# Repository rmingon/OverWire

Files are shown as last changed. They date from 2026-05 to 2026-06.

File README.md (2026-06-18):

# OverWire

**Cut the cord, keep the control.** 
OverWire is a specialized, open-source hardware bridge designed to liberate your STM32 development process. By coupling a powerful ESP32-WROOM-32 module with a dedicated SWD (Serial Wire Debug) interface, OverWire allows you to flash and debug STM32 targets completely wirelessly.

Whether your target is locked inside an enclosure, mounted on a moving robot, or just sitting across the room, OverWire brings the programming interface directly to you over Wi-Fi.

### Real
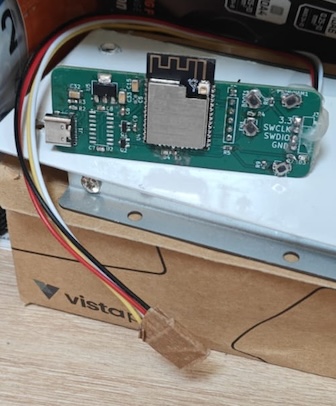
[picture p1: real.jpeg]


---
## Features

* **ESP32 at the Core:** Powered by the robust ESP32-WROOM-32 module, providing reliable 2.4 GHz Wi-Fi and Bluetooth connectivity for Over-The-Air (OTA) target flashing.
* **Dedicated SWD Port:** A clean 4-pin header (`3.3V`, `SWCLK`, `SWDIO`, `GND`) ready to hook directly into your STM32 target.
* **USB Type-C Interface:** Modern USB-C connector backed by a CH340C USB-to-UART bridge for painless initial flashing and serial debugging of the ESP32 itself.
* **Auto-Program Circuit:** Features the standard dual-BSS138 (DTR/RTS) auto-reset circuit, meaning you don't need to hold down buttons to flash the ESP32.
* **On-Board LDO:** AMS1117-3.3V regulator safely steps down the 5V USB power to a stable 3.3V for the ESP32 and SWD target.
* **Tactile Control:** Includes `EN` and `BOOT` buttons for the ESP32, plus two programmable user buttons (`TOP1`, `PROGRAM1`) mapped to `IO15` and `IO16` for custom firmware triggers.
* **Status LEDs:** Two user-controllable LEDs mapped to `IO12` and `IO13` for quick visual feedback (e.g., Wi-Fi connected, Flashing target, Error).

## Pinout & Connections

### Target SWD Interface (J3)
| Pin | Name | Description |
| :--- | :--- | :--- |
| 1 | **+3V3** | 3.3V Power Output to target (from AMS1117) |
| 2 | **SWCLK** | Serial Wire Clock (Connects to ESP32) |
| 3 | **SWDIO** | Serial Wire Debug Data I/O (Connects to ESP32) |
| 4 | **GND** | Common Ground |

### Extension / Debug Header (J2)
Provides access to `5V`, `GND`, and the ESP32 UART (`TX-PROG`, `RX-PROG`) for external communication or secondary programming.

## Gallery

### 3D Render
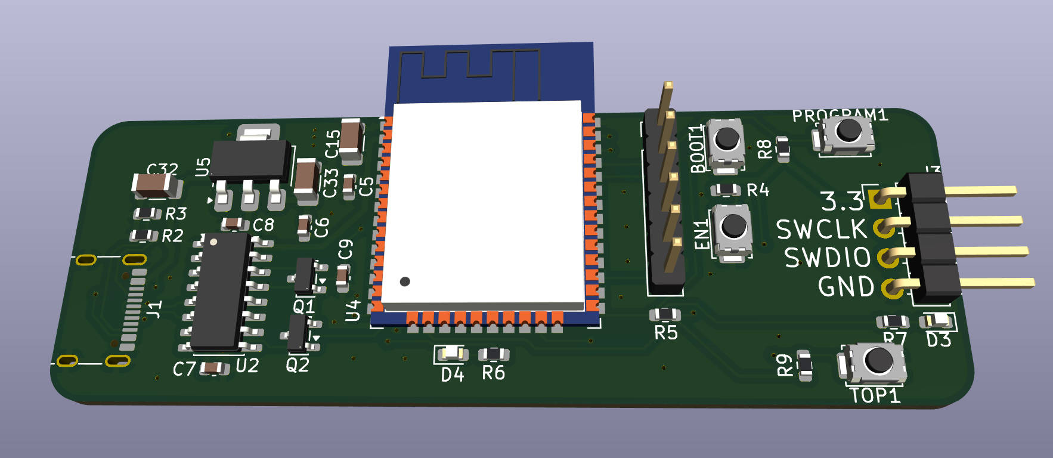
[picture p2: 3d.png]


### PCB Layout
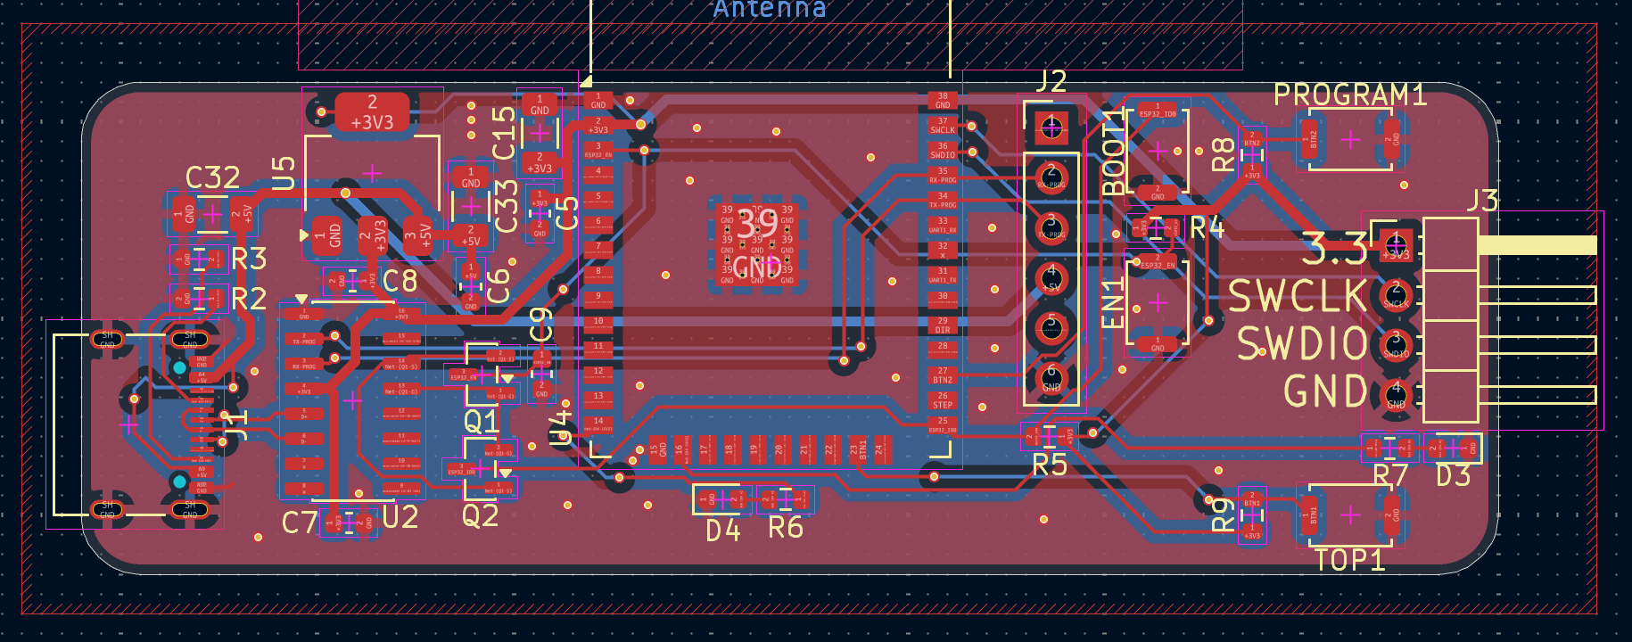
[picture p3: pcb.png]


### Schematic
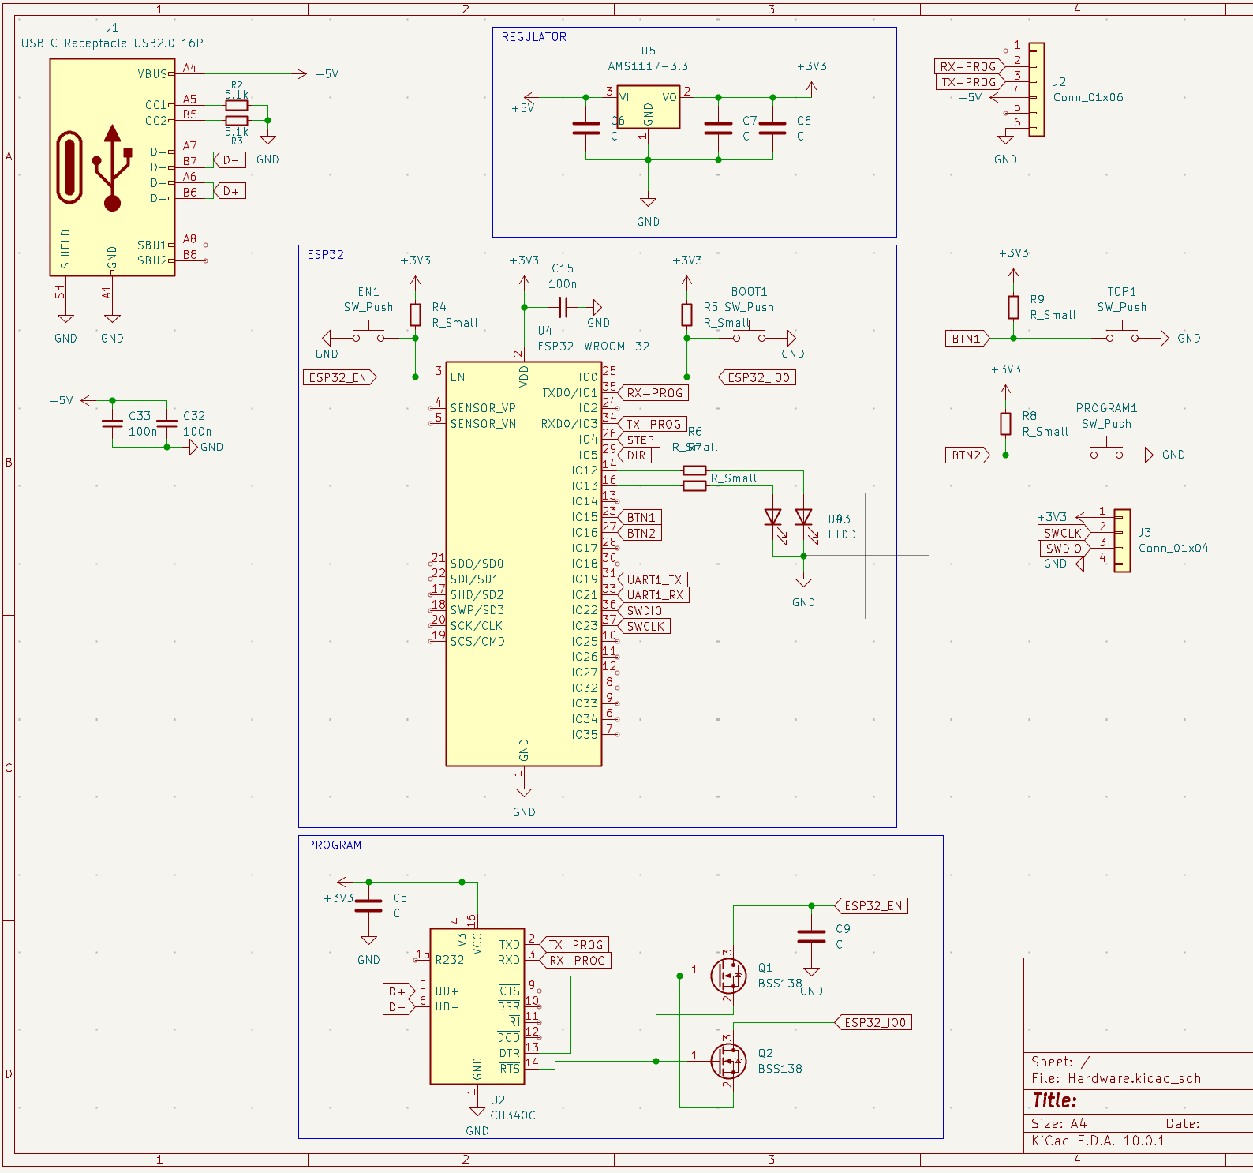
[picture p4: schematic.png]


## Getting Started

1. Connect OverWire to your PC via a USB Type-C cable.
2. Flash the ESP32 with your preferred wireless SWD firmware (such as a Wi-Fi BlackMagic Probe port or custom TCP-to-SWD bridge).
3. Connect the `J3` SWD header to your STM32 target.
4. Connect to the ESP32 over Wi-Fi and start flashing your STM32 remotely!

---

## License

This hardware design is released under the **Creative Commons Attribution-NonCommercial 4.0 International** (CC BY-NC 4.0) license. 
You are free to view, use, and modify this design for **personal, non-commercial** purposes only. You may **not** use this material for commercial purposes (such as manufacturing and selling the boards) without explicit written permission from the original author.

*Designed with KiCad.*

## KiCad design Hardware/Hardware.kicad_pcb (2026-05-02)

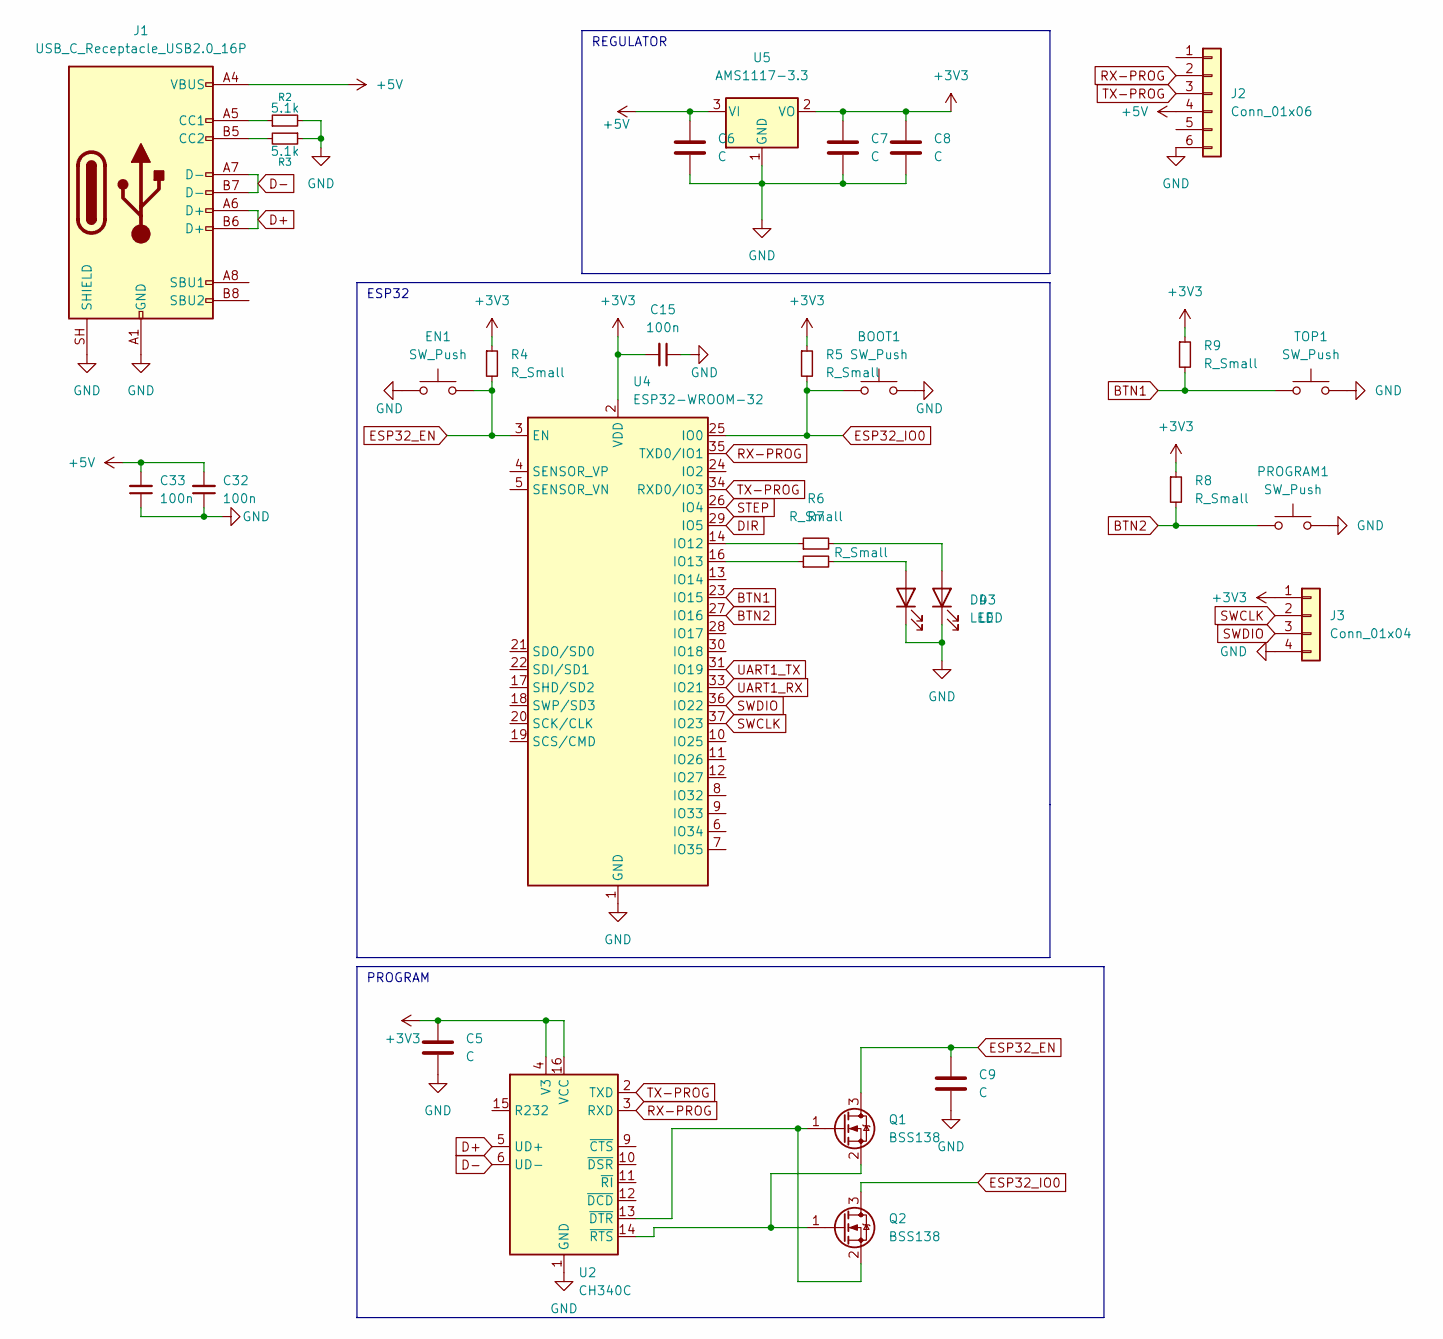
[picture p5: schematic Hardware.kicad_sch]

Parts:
BOOT1: SW_Push; SW_Push_SPST_NO_Alps_SKRK; LCSC C398053
C5, C6, C8: C; C_0603_1608Metric; LCSC C30926
C7, C9: C; C_0603_1608Metric; LCSC C19702
C15, C32, C33: 100n; C_1206_3216Metric
D3: LED; LED_0603_1608Metric; LCSC C19171301
D4: LED; LED_0603_1608Metric; LCSC C434425
EN1: SW_Push; SW_Push_SPST_NO_Alps_SKRK; LCSC C398053
J1: USB_C_Receptacle_USB2.0_16P; USB_C_Receptacle_G-Switch_GT-USB-7010ASV
J2: Conn_01x06; PinHeader_1x06_P2.54mm_Vertical
J3: Conn_01x04; PinHeader_1x04_P2.54mm_Horizontal
PROGRAM1: SW_Push; SW_Push_SPST_NO_Alps_SKRK; LCSC C398053
Q1, Q2: BSS138; SOT-23; LCSC C7420338
R2, R3: 5.1k; R_0603_1608Metric
R4, R5, R8, R9: R_Small; R_0603_1608Metric; LCSC C98220
R6, R7: R_Small; R_0603_1608Metric; LCSC C2906975
TOP1: SW_Push; SW_Push_SPST_NO_Alps_SKRK; LCSC C398053
U2: CH340C; SOIC-16_3.9x9.9mm_P1.27mm; LCSC C84681
U4: ESP32-WROOM-32; LCSC C82899
U5: AMS1117-3.3; SOT-223-3_TabPin2; LCSC C6186

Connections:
+3V3: C5.1, C7.1, C8.1, C15.2, J3.1, R4.1, R5.1, R8.1, R9.1, U2.4 (V3), U2.16 (VCC), U4.2 (VDD), U5.2 (VO)
+5V: C6.1, C32.2, C33.2, J1.A4 (VBUS), J1.A9 (VBUS), J1.B4 (VBUS), J1.B9 (VBUS), J2.4, U5.3 (VI)
BTN1: R9.2, TOP1.1, U4.23 (IO15)
BTN2: PROGRAM1.1, R8.2, U4.27 (IO16)
D+: J1.A6 (D+), J1.B6 (D+), U2.5 (UD+)
D-: J1.A7 (D-), J1.B7 (D-), U2.6 (UD-)
DIR: U4.29 (IO5)
ESP32_EN: C9.1, EN1.2, Q1.3 (D), R4.2, U4.3 (EN)
ESP32_IO0: BOOT1.1, Q2.3 (D), R5.2, U4.25 (IO0)
GND: BOOT1.2, C5.2, C6.2, C7.2, C8.2, C9.2, C15.1, C32.1, C33.1, D3.1 (K), D4.1 (K), EN1.1, J1.A1 (GND), J1.A12 (GND), J1.B1 (GND), J1.B12 (GND), J1.SH (SHIELD), J2.6, J3.4, PROGRAM1.2, R2.2, R3.1, TOP1.2, U2.1 (GND), U4.1 (GND), U4.15 (GND), U4.38 (GND), U4.39 (GND), U5.1 (GND)
unnamed: D3.2 (A), R7.2
unnamed: D4.2 (A), R6.2
unnamed: J1.A5 (CC1), R2.1
unnamed: J1.B5 (CC2), R3.2
unnamed: Q1.1 (G), Q2.2 (S), U2.13 (~DTR)
unnamed: Q1.2 (S), Q2.1 (G), U2.14 (~RTS)
unnamed: R6.1, U4.14 (IO12)
unnamed: R7.1, U4.16 (IO13)
RX-PROG: J2.2, U2.3 (RXD), U4.35 (TXD0/IO1)
STEP: U4.26 (IO4)
SWCLK: J3.2, U4.37 (IO23)
SWDIO: J3.3, U4.36 (IO22)
TX-PROG: J2.3, U2.2 (TXD), U4.34 (RXD0/IO3)
UART1_RX: U4.33 (IO21)
UART1_TX: U4.31 (IO19)

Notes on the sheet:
REGULATOR
ESP32
PROGRAM

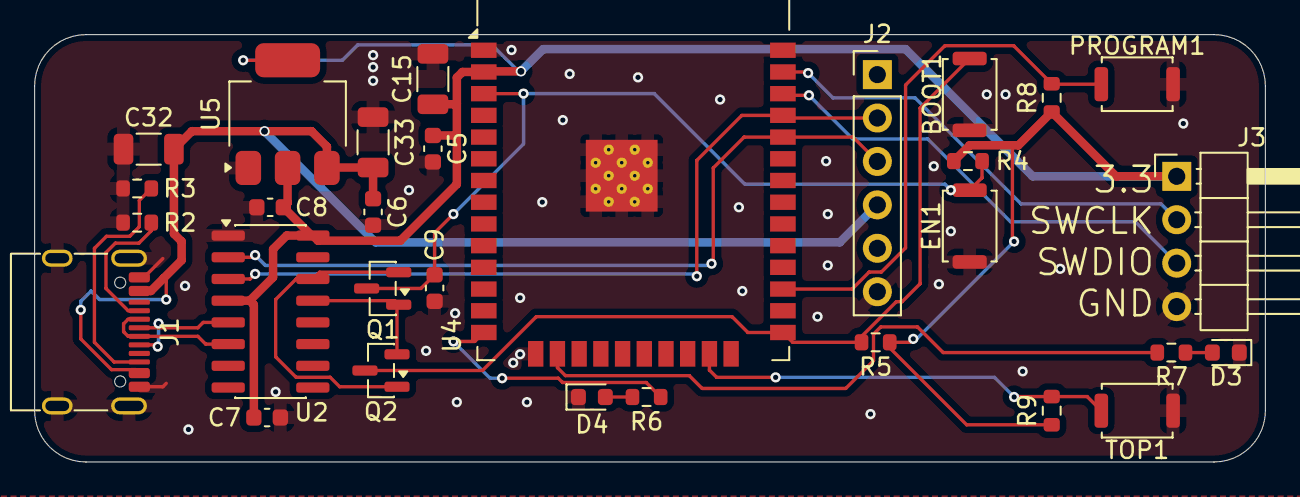
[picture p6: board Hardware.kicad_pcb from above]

Board: 2 copper layers, 72.0 x 25.0 mm, 30 parts (0 on the bottom side), 21 nets.

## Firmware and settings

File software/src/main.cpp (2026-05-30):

#include <Arduino.h>
#include <WiFi.h>
#include <ESPAsyncWebServer.h>
#include <LittleFS.h>

// --- Configuration ---
#define SWDIO_PIN 23
#define SWCLK_PIN 22
#define BUTTON_PIN 16
#define BUZZER_PIN 12               // active buzzer: drive HIGH to sound
#define LED_FAILURE_PIN 13
#define LED_HEARTBEAT_PIN LED_FAILURE_PIN // Using LED_FAILURE_PIN for heartbeat
#define FIRMWARE_PATH "/firmware.bin"
#define LOG_PATH "/uids.csv"

// Registers and Constants
#define STM32_UID_ADDR  0x1FFFF7E8
#define FLASH_F1_KEYR   0x40022004
#define FLASH_F1_SR     0x4002200C
#define FLASH_F1_CR     0x40022010
#define FLASH_KEY1      0x45670123
#define FLASH_KEY2      0xCDEF89AB

#define DP_SELECT       0x08
#define DP_RDBUFF       0x0C
#define DP_CTRLSTAT     0x04
#define AP_CSW          0x00
#define AP_TAR          0x04
#define AP_DRW          0x0C

#define DHCSR_ADDR      0xE000EDF0
#define DHCSR_HALT      0xA05F0003  // DBGKEY | C_DEBUGEN | C_HALT

#define SWD_DELAY_US   0
#define SWD_NOPS       0

AsyncWebServer server(80);
bool isProgramming = false;
unsigned long lastHeartbeat = 0;
const uint32_t heartbeatInterval = 500; // Blink every 500ms

// --- SWD Protocol Implementation ---
#define SWCLK_H()    digitalWrite(SWCLK_PIN, HIGH)
#define SWCLK_L()    digitalWrite(SWCLK_PIN, LOW)
#define SWDIO_H()    digitalWrite(SWDIO_PIN, HIGH)
#define SWDIO_L()    digitalWrite(SWDIO_PIN, LOW)
#define SWDIO_SET(b) digitalWrite(SWDIO_PIN, (b) ? HIGH : LOW)
#define SWDIO_RD()   (digitalRead(SWDIO_PIN) != 0)
#define SWDIO_OE()   pinMode(SWDIO_PIN, OUTPUT)        // drive
#define SWDIO_IE()   pinMode(SWDIO_PIN, INPUT_PULLUP)  // release (pull-up holds high)

// Configure SWD pins once.
void swd_gpio_init() {
    pinMode(SWCLK_PIN, OUTPUT);
    SWCLK_L();
    SWDIO_OE();
    SWDIO_H();   // idle/park level
}

inline void swd_delay() {
    if (SWD_DELAY_US) delayMicroseconds(SWD_DELAY_US);
    for (volatile int i = 0; i < SWD_NOPS; i++) { /* burn ~25ns each */ }
}

inline void swd_clk() {
    swd_delay();
    SWCLK_H();
    swd_delay();
    SWCLK_L();
}

void swd_seq(uint32_t bits, int n) {
    SWDIO_OE();
    for (int i = 0; i < n; i++) {
        SWDIO_SET((bits >> i) & 1);
        swd_clk();
    }
}

void swd_line_reset() {
    swd_seq(0xFFFFFFFF, 32);
    swd_seq(0xFFFFFFFF, 32);
}

void swd_idle_clocks() {
    swd_seq(0, 12);
}

uint8_t swd_header(bool ap, bool read, uint8_t a32) {
    bool par = (ap ? 1 : 0) ^ (read ? 1 : 0) ^ (a32 & 1) ^ ((a32 >> 1) & 1);
    SWDIO_OE();
    SWDIO_H();              swd_clk(); // Start = 1
    SWDIO_SET(ap);          swd_clk(); // APnDP
    SWDIO_SET(read);        swd_clk(); // RnW
    SWDIO_SET(a32 & 1);     swd_clk(); // A[2]
    SWDIO_SET((a32 >> 1) & 1); swd_clk(); // A[3]
    SWDIO_SET(par);         swd_clk(); // Parity
    SWDIO_L();              swd_clk(); // Stop = 0
    SWDIO_IE();                        // Park: release line
    swd_clk();                         // Park cycle
    swd_clk();                         // Turnaround
    uint8_t ack = 0;
    if (SWDIO_RD()) ack |= 1; swd_clk(); // ACK[0]
    if (SWDIO_RD()) ack |= 2; swd_clk(); // ACK[1]
    if (SWDIO_RD()) ack |= 4; swd_clk(); // ACK[2] + trailing clock
    return ack;
}

uint8_t swd_xfer(bool ap, bool read, uint8_t a32, uint32_t *val) {
    uint8_t ack = swd_header(ap, read, a32);
    if (ack != 1) {
        if (ack != 2 && ack != 4) for (int i = 0; i < 33; i++) swd_clk();
        swd_seq(0, 8);
        return ack;
    }

    if (read) { // RDATA[0] already on the line
        uint32_t v = 0; uint8_t ones = 0;
        for (int i = 0; i < 32; i++) {
            if (SWDIO_RD()) { v |= (1UL << i); ones++; }
            swd_clk();
        }
        uint8_t pbit = SWDIO_RD() ? 1 : 0;
        swd_clk();
        swd_seq(0, 8);                 // turnaround back to host + idle
        if ((ones & 1) != pbit) return 0xFF;
        if (val) *val = v;
    } else { // one turnaround, then host drives WDATA
        swd_clk();
        SWDIO_OE();
        uint32_t v = val ? *val : 0; uint8_t ones = 0;
        for (int i = 0; i < 32; i++) {
            bool b = (v >> i) & 1;
            SWDIO_SET(b);
            if (b) ones++;
            swd_clk();
        }
        SWDIO_SET(ones & 1);           // even parity
        swd_clk();
        swd_seq(0, 8);                 // idle
    }
    return 1;
}

// Clear DP sticky error flags via ABORT (always accepted, even in FAULT state).
void swd_clear_errors() {
    uint32_t ab = 0x1E; // ORUNERRCLR|WDERRCLR|STKERRCLR|STKCMPCLR
    swd_xfer(false, false, 0, &ab);
}

bool swd_read_reg(bool ap, uint8_t addr, uint32_t *val) {
    uint8_t a32 = (addr >> 2) & 3;
    for (int attempt = 0; attempt < 16; attempt++) {
        uint8_t ack = swd_xfer(ap, true, a32, val);
        if (ack == 1) return true;
        if (ack == 4) swd_clear_errors();   // FAULT: clear sticky flags before retry
    }
    Serial.printf("[SWD] read giving up ap=%d a32=%d\n", ap, a32);
    return false;
}

bool swd_write_reg(bool ap, uint8_t addr, uint32_t val) {
    uint8_t a32 = (addr >> 2) & 3;
    for (int attempt = 0; attempt < 16; attempt++) {
        uint8_t ack = swd_xfer(ap, false, a32, &val);
        if (ack == 1) return true;
        if (ack == 4) swd_clear_errors();
    }
    Serial.printf("[SWD] write giving up ap=%d a32=%d\n", ap, a32);
    return false;
}

bool swd_mem_access(uint32_t addr, uint32_t *val, bool write, uint32_t size_bits) {
    uint32_t csw = 0x23000000 | (size_bits == 16 ? 1 : 2); // 1=16bit, 2=32bit
    if (!swd_write_reg(false, DP_SELECT, 0)) return false;
    if (!swd_write_reg(true, AP_CSW, csw)) return false;
    if (!swd_write_reg(true, AP_TAR, addr)) return false;
    if (write) return swd_write_reg(true, AP_DRW, *val);
    uint32_t dummy;
    if (!swd_read_reg(true, AP_DRW, &dummy)) return false;
    return swd_read_reg(false, DP_RDBUFF, val);
}

bool ap_write(uint32_t addr, uint32_t val) {
    if (!swd_write_reg(true, AP_TAR, addr)) return false;
    return swd_write_reg(true, AP_DRW, val);
}
bool ap_read(uint32_t addr, uint32_t *val) {
    if (!swd_write_reg(true, AP_TAR, addr)) return false;
    uint32_t dummy;
    if (!swd_read_reg(true, AP_DRW, &dummy)) return false;
    return swd_read_reg(false, DP_RDBUFF, val);
}

bool init_swd_connection() {
    swd_gpio_init();

    // line reset -> 16-bit select sequence -> line reset -> >=12 idle zeros.
    swd_line_reset();
    swd_seq(0xE79E, 16); // 0x79E7 MSB-first == 0xE79E LSB-first
    swd_line_reset();
    swd_idle_clocks();

    // First transaction after reset MUST be a DPIDR read; it never returns FAULT.
    uint32_t idcode = 0;
    if (!swd_read_reg(false, 0x00, &idcode)) {
        Serial.println("No IDCODE — check wiring (SWDIO=PA13, SWCLK=PA14), pull-up on SWDIO, and SWD_DELAY_US");
        return false;
    }
    Serial.printf("IDCODE: 0x%08X\n", idcode);

    // Clear any sticky error flags (ABORT: ORUNERRCLR|WDERRCLR|STKERRCLR|STKCMPCLR)
    swd_write_reg(false, 0x00, 0x1E);

    if (!swd_write_reg(false, DP_CTRLSTAT, 0x50000000)) {
        Serial.println("CTRL/STAT write failed");
        return false;
    }
    uint32_t ctrl = 0;
    uint32_t timeout = 1000;
    bool printed = false;
    while (timeout--) {
        if (!swd_read_reg(false, DP_CTRLSTAT, &ctrl)) {
            Serial.println("CTRL/STAT read failed");
            return false;
        }
        if (!printed) { Serial.printf("CTRL/STAT = 0x%08X\n", ctrl); printed = true; }
        if ((ctrl & 0xA0000000) == 0xA0000000) {
            Serial.println("Powered up.");
            return true;
        }
        delay(1);
    }
    Serial.printf("Power-up ACK timeout, CTRL/STAT = 0x%08X\n", ctrl);
    return false;
}

// timeout_ms: use a large value for mass erase (up to ~40s on STM32F1)
bool wait_flash_busy(uint32_t timeout_ms = 1000) {
    uint32_t sr = 0;
    while (timeout_ms--) {
        if (!swd_mem_access(FLASH_F1_SR, &sr, false, 32)) return false;
        if (!(sr & 0x01)) return true; // BSY cleared
        delay(1);
    }
    return false;
}

bool unlock_flash() {
    uint32_t key1 = FLASH_KEY1;
    uint32_t key2 = FLASH_KEY2;
    if (!swd_mem_access(FLASH_F1_KEYR, &key1, true, 32)) return false;
    if (!swd_mem_access(FLASH_F1_KEYR, &key2, true, 32)) return false;
    return true;
}

String get_stm32_uid() {
    uint32_t u1, u2, u3;
    if (swd_mem_access(STM32_UID_ADDR, &u1, false, 32) &&
        swd_mem_access(STM32_UID_ADDR + 4, &u2, false, 32) &&
        swd_mem_access(STM32_UID_ADDR + 8, &u3, false, 32)) {
        char buf[32];
        sprintf(buf, "%08X%08X%08X", u1, u2, u3);
        return String(buf);
    }
    return "UNKNOWN_UID";
}

bool flash_relink(uint32_t csw16) {
    Serial.println("[SWD] frame desync - re-syncing link");
    if (!init_swd_connection()) return false;      // line reset, switch, IDCODE, power-up
    uint32_t dhcsr = DHCSR_HALT;                    // re-halt (debug power may have cycled)
    for (int i = 0; i < 50; i++) {
        swd_mem_access(DHCSR_ADDR, &dhcsr, true, 32);
        uint32_t s = 0;
        if (swd_mem_access(DHCSR_ADDR, &s, false, 32) && (s & (1UL << 17))) break;
    }
    swd_clear_errors();
    swd_write_reg(false, DP_SELECT, 0);            // restore AP context
    swd_write_reg(true, AP_CSW, csw16);
    uint32_t pg = 0x01;
    ap_write(FLASH_F1_CR, pg);                     // re-assert PG
    return true;
}

bool flash_stm32(String filePath) {
    File file = LittleFS.open(filePath, "r");
    if (!file) return false;

    Serial.println("Starting Flash Process...");

    uint32_t dhcsr = DHCSR_HALT;
    bool halted = false;
    for (int i = 0; i < 50; i++) {
        swd_mem_access(DHCSR_ADDR, &dhcsr, true, 32);  // assert C_HALT | C_DEBUGEN
        uint32_t s = 0;
        if (swd_mem_access(DHCSR_ADDR, &s, false, 32) && (s & (1UL << 17))) { // S_HALT
            halted = true;
            break;
        }
    }
    if (!halted) {
        Serial.println("Failed to halt CPU");
        file.close();
        return false;
    }
    Serial.println("CPU halted.");
    swd_clear_errors();  // clear anything the pre-halt run may have set

    if (!unlock_flash()) { file.close(); return false; }

    if (!wait_flash_busy(500)) { file.close(); return false; }
    uint32_t cr_val = 0x04; // MER
    swd_mem_access(FLASH_F1_CR, &cr_val, true, 32);
    cr_val = 0x44; // MER | STRT
    swd_mem_access(FLASH_F1_CR, &cr_val, true, 32);
    if (!wait_flash_busy(60000)) { // 60s timeout for mass erase
        Serial.println("Mass erase timeout");
        file.close();
        return false;
    }

    swd_clear_errors();                          // clear anything mass-erase left set
    swd_write_reg(false, DP_SELECT, 0);          // AP bank 0 (once)
    uint32_t csw16 = 0x23000001;                 // debug master, privileged, 16-bit access
    swd_write_reg(true, AP_CSW, csw16);
    cr_val = 0x01;                               // PG: programming enable (stays set)
    ap_write(FLASH_F1_CR, cr_val);

    uint32_t addr = 0x08000000;
    size_t total = file.size();
    size_t written = 0;
    const size_t BLOCK_SIZE = 1024;       // one STM32F1 flash page = progress unit
    size_t nextBlock = BLOCK_SIZE;
    Serial.printf("Programming %u bytes -> 0x08000000\n", (unsigned)total);

    while (file.available()) {
        uint16_t hw = 0xFFFF;              // pad a trailing odd byte with 0xFF
        int n = file.read((uint8_t*)&hw, 2);
        if (n <= 0) break;

        uint32_t data = ((uint32_t)hw << 16) | hw;

        bool ok = false;
        for (int attempt = 0; attempt < 4 && !ok; attempt++) {
            if (attempt > 0) {
                if (!flash_relink(csw16)) { file.close(); return false; }
                uint32_t rb = 0;
                if (ap_read(addr, &rb)) {
                    uint16_t got = (addr & 2) ? (rb >> 16) : (rb & 0xFFFF);
                    if (got == hw) { ok = true; break; }   // already written
                }
            }
            if (!ap_write(addr, data)) continue;           // write failed -> relink & retry

            // Wait for BSY=0 AND read error bits from the SAME status read.
            uint32_t sr = 0; bool busyCleared = false;
            for (int i = 0; i < 2000; i++) {
                if (!ap_read(FLASH_F1_SR, &sr)) break;     // read failed -> relink & retry
                if (!(sr & 0x01)) { busyCleared = true; break; }
            }
            if (!busyCleared) continue;                    // timeout/read fail -> relink & retry
            if (sr & 0x14) { // PGERR (bit2) | WRPRTERR (bit4) — a real programming error
                Serial.printf("Flash error SR=0x%04X at 0x%08X\n", sr, addr);
                file.close(); return false;
            }
            ok = true;
        }
        if (!ok) { Serial.printf("Write fail at 0x%08X\n", addr); file.close(); return false; }

        addr += 2;
        written += (n < 2) ? n : 2;

        // One block done (or final bytes): print address + percent, quick LED blink
        if (written >= nextBlock || !file.available()) {
            unsigned pct = total ? (unsigned)((written * 100) / total) : 100;
            Serial.printf("  0x%08X  %6u / %u bytes  (%3u%%)\n",
                          addr, (unsigned)written, (unsigned)total, pct);
            digitalWrite(LED_FAILURE_PIN, HIGH);
            delay(8);
            digitalWrite(LED_FAILURE_PIN, LOW);
            nextBlock += BLOCK_SIZE;
        }
    }

    cr_val = 0x80;                        // LOCK
    ap_write(FLASH_F1_CR, cr_val);

    Serial.printf("Programming complete: %u bytes, ended at 0x%08X\n",
                  (unsigned)written, addr);
    file.close();
    return true;
}

bool verify_stm32(String filePath) {
    File file = LittleFS.open(filePath, "r");
    if (!file) return false;

    swd_write_reg(false, DP_SELECT, 0);          // AP bank 0
    uint32_t csw32 = 0x23000002;                 // 32-bit access for fast word reads
    swd_write_reg(true, AP_CSW, csw32);

    uint32_t addr = 0x08000000;
    size_t total = file.size(), checked = 0, nextReport = 8192;
    Serial.printf("Verifying %u bytes...\n", (unsigned)total);

    while (file.available()) {
        uint32_t expected = 0xFFFFFFFF;          // unread tail bytes are erased 0xFF
        int n = file.read((uint8_t*)&expected, 4);
        if (n <= 0) break;

        uint32_t got = 0;
        if (!ap_read(addr, &got)) {
            Serial.printf("Verify read fail at 0x%08X\n", addr);
            file.close(); return false;
        }
        if (got != expected) {
            Serial.printf("VERIFY MISMATCH at 0x%08X: flash=0x%08X expected=0x%08X\n",
                          addr, got, expected);
            file.close(); return false;
        }
        addr += 4;
        checked += (n < 4) ? n : 4;
        if (checked >= nextReport) {
            Serial.printf("  verified %u / %u bytes\n", (unsigned)checked, (unsigned)total);
            nextReport += 8192;
        }
    }
    file.close();
    Serial.printf("Verify OK: %u bytes match.\n", (unsigned)checked);
    return true;
}

void stm32_run() {
    uint32_t v;
    v = 0x00000000; swd_mem_access(0xE000EDFC, &v, true, 32); // DEMCR: clear vector catch
    v = 0x05FA0004; swd_mem_access(0xE000ED0C, &v, true, 32); // AIRCR: SYSRESETREQ (reboot)
    delay(10);                                                 // let the reset complete
    v = 0xA05F0000; swd_mem_access(DHCSR_ADDR, &v, true, 32);  // DHCSR: C_HALT=0, C_DEBUGEN=0
    Serial.println("Target reset and running.");
}

void log_uid(String uid) {
    File file = LittleFS.open(LOG_PATH, FILE_APPEND);
    if (file) {
        file.printf("%lu,%s\n", millis(), uid.c_str());
        file.close();
        Serial.println("UID logged: " + uid);
    }
}

void buzzer_beep(int count, int on_ms, int off_ms) {
    for (int i = 0; i < count; i++) {
        digitalWrite(BUZZER_PIN, HIGH);
        delay(on_ms);
        digitalWrite(BUZZER_PIN, LOW);
        if (i < count - 1) delay(off_ms);
    }
}

void run_programming_sequence() {
    if (isProgramming) return;
    isProgramming = true;
    Serial.println("Starting sequence...");

    digitalWrite(BUZZER_PIN, LOW);

    if (init_swd_connection()) {
        String uid = get_stm32_uid();
        Serial.println("Target UID: " + uid);
        if (flash_stm32(FIRMWARE_PATH) && verify_stm32(FIRMWARE_PATH)) {
            stm32_run();
            log_uid(uid);
            Serial.println("Success!");
            buzzer_beep(2, 120, 100);
        } else {
            Serial.println("Failed to program/verify Flash.");
            buzzer_beep(1, 800, 0); 
        }
    } else {
        Serial.println("Failed to connect to STM32.");
        buzzer_beep(1, 800, 0); 
    }
    isProgramming = false;
}

// --- Web Interface HTML ---
const char index_html[] PROGMEM = R"rawliteral(
<!DOCTYPE HTML><html><head>
  <title>ESP32 SWD Programmer</title>
  <meta name="viewport" content="width=device-width, initial-scale=1">
  <style>
    body { font-family: Arial; text-align: center; margin: 0 auto; padding-top: 30px; }
    .btn { background-color: #008CBA; color: white; padding: 10px 20px; text-decoration: none; border-radius: 4px; }
    .log-btn { background-color: #4CAF50; }
  </style>
</head><body>
  <h1>STM32 Programmer</h1>
  <form method="POST" action="/upload" enctype="multipart/form-data">
    <input type="file" name="update">
    <input type="submit" value="Upload Firmware">
  </form>
  <br><br>
  <a href="/download" class="btn log-btn">Download UID Log (CSV)</a>
  <p>Press the physical button on IO16 to start programming.</p>
</body></html>
)rawliteral";

void setup() {
    Serial.begin(115200);
    pinMode(BUTTON_PIN, INPUT_PULLUP);
    pinMode(LED_FAILURE_PIN, OUTPUT);
    digitalWrite(LED_FAILURE_PIN, LOW);
    pinMode(LED_HEARTBEAT_PIN, OUTPUT);

    if (!LittleFS.begin(true)) {
        Serial.println("LittleFS Mount Failed");
        return;
    }

    WiFi.softAP("ESP32_Programmer", "12345678");
    Serial.println("AP Started. IP: " + WiFi.softAPIP().toString());

    // Web Server Routes
    server.on("/", HTTP_GET, [](AsyncWebServerRequest *request){
        request->send(200, "text/html", index_html);
    });

    server.on("/upload", HTTP_POST, [](AsyncWebServerRequest *request){
        request->send(200, "text/plain", (LittleFS.exists(FIRMWARE_PATH)) ? "Upload Success" : "Upload Failed");
    }, [](AsyncWebServerRequest *request, String filename, size_t index, uint8_t *data, size_t len, bool final){
        if (!index) {
            request->_tempFile = LittleFS.open(FIRMWARE_PATH, "w");
        }
        if (request->_tempFile) {
            request->_tempFile.write(data, len);
        }
        if (final) {
            request->_tempFile.close();
        }
    });

    server.on("/download", HTTP_GET, [](AsyncWebServerRequest *request){
        request->send(LittleFS, LOG_PATH, "text/csv");
    });

    server.begin();
}

void loop() {
    unsigned long currentMillis = millis();
    if (currentMillis - lastHeartbeat >= heartbeatInterval) {
        lastHeartbeat = currentMillis;
        digitalWrite(LED_HEARTBEAT_PIN, !digitalRead(LED_HEARTBEAT_PIN));
    }

    if (digitalRead(BUTTON_PIN) == LOW) {
        delay(50); // Debounce
        if (digitalRead(BUTTON_PIN) == LOW) {
            run_programming_sequence();
            while(digitalRead(BUTTON_PIN) == LOW); // Wait for release
        }
    }
}

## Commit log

2026-05-01 move usb C
    [Hardware.kicad_pcb]
2026-05-02 end position pcb
    [Hardware.kicad_pcb, Hardware.kicad_sch]
2026-05-02 finish pcb wiring
    [Hardware.kicad_pcb, Hardware.kicad_sch]
